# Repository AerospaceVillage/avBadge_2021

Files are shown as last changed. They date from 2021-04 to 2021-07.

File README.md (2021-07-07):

# Aerospace Village Badge 2021

This repository is to document and capture all of the engineering and design work that went into creating the [Aerospace Village](https://aerospacevillage.org) Badge for DefCon 2021.

We hope you enjoy all of the ways to interact with this years badge and learn about Aerospace along the way!

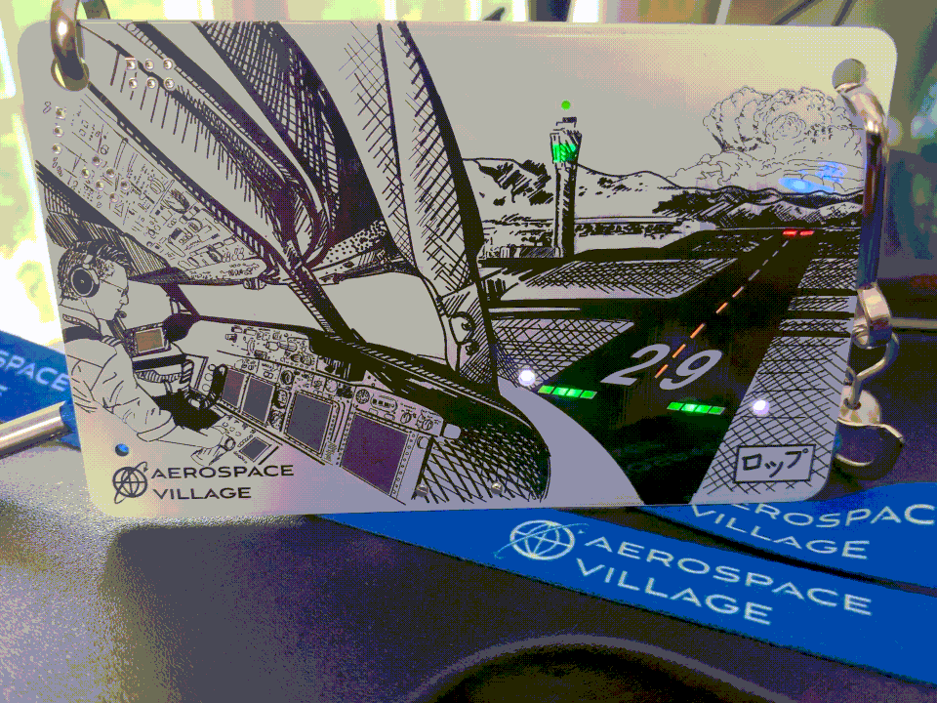
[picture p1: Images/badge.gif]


## Kit Assembly

Instructions for assembling a kit can be found in the Document folder.

  - [Tindie Instructions](https://github.com/daneallen/avBadge_2021/blob/master/Documents/av_badge2021_instructions.pdf)
  - [Instructions sent with kit](https://github.com/daneallen/avBadge_2021/blob/master/Documents/av_badge2021_kit_instructions.pdf)

  ## Arduino Programming
  Using the Arduino IDE Add the correct Boards Manager URL:

      - Under File->Preferences add the following URL https://mcudude.github.io/MiniCore/package_MCUdude_MiniCore_index.json
      - Then with the new Boards Manager options select MiniCore
          - Select the Atmega88

  Steps:

      - Programmer - USBTinyISP
      - Clock - Internal 8MHZ
      - Bootloader - "No bootloader" (Not enough memory to support the bootloader)
      - Sketch -> Upload

      ## AVR Programming

[device permissions help](https://andreasrohner.at/posts/Electronics/How-to-fix-device-permissions-for-the-USBasp-programmer/)

[ttyACM permission](https://stackoverflow.com/questions/40951728/avrdude-ser-open-cant-open-device-dev-ttyacm0-device-or-resource-busy)

```
sudo adduser <username> dialout
$ sudo chmod a+rw /dev/ttyACM0
```

## Hardware
The ATMega88 is programmed with the [Sparkfun Tiny AVR Programmer](https://www.sparkfun.com/products/11801) using the [SparkFun ISP Pogo Adapter](https://www.sparkfun.com/products/11591)

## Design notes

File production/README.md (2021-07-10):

# Production Notes

For ease of mass production a script was made to quickly and reliably program the boards.

The script does the folliwing:
1. Sets the fuses appropriately (i.e. internal 8MHz, etc).
2. Burns a hex file to the chip that essentially ensures the EEPROM address is set to 0.
  - This was to ensure that a "test" part of the code would run to verify LED functionality prior to shipment
3. Burns the actual hex file to the chip

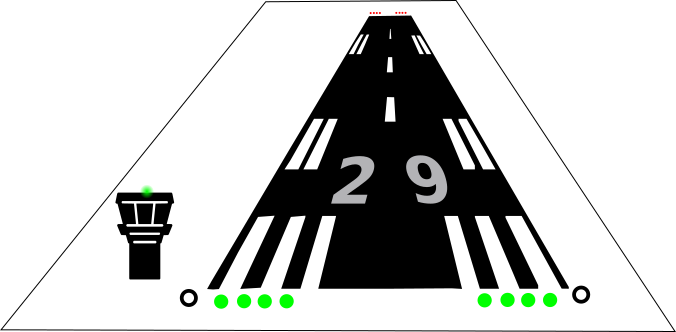
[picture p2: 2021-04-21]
Images/airport_idea.png

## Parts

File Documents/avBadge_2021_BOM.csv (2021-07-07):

Reference | Quantity | Value | Footprint
BT1 | 1 | Battery_Cell | 2479_battery_holder:2479
C1 C2 | 2 | .1uF | Resistors_SMD:R_1206_3216Metric
D1 D2 | 2 | SunLED_RGB_ReverseMount | sunled:XZMDKCBDDG45S-9
D10 D11 D12 | 3 | Yellow LED | sunled:XZMYK45WT-9
D4 D9 | 2 | Blue LED | sunled:XZFBB45S-9
D3 D5 | 2 | White LED | aerospace_badge:led_in-s124ar
D6 D7 | 2 | Green LED | sunled:XZM2CRK45WT-9
D8 | 1 | Red LED | sunled:XZDGK45WT-9
J1 | 1 | AVR-ISP-6 | aerospace_badge:AVR-ISP-6
P1 | 1 | SerialConnector | aerospace_badge:serialConnector
Q1 | 1 | 2N3904 | aerospace_badge:SOT-23-NPN
R13 | 1 | 1K | Resistors_SMD:R_1206_3216Metric
R1 R2 R3 R4 R5 R6 R8 R10 R11 R14 R15 R16 R17 R18 R19 R20 | 16 | 330 | Resistors_SMD:R_1206_3216Metric
R7 R9 R12 | 3 | 10K | Resistors_SMD:R_1206_3216Metric
S1 | 1 | OpenConnections | aerospace_badge:artboard_smooth2
SW1 | 1 | SW_SPDT | aerospace_badge:switch_JS202011SCQN
U1 | 1 | ATmega8-16AU | digikey-footprints:TQFP-32_7x7mm

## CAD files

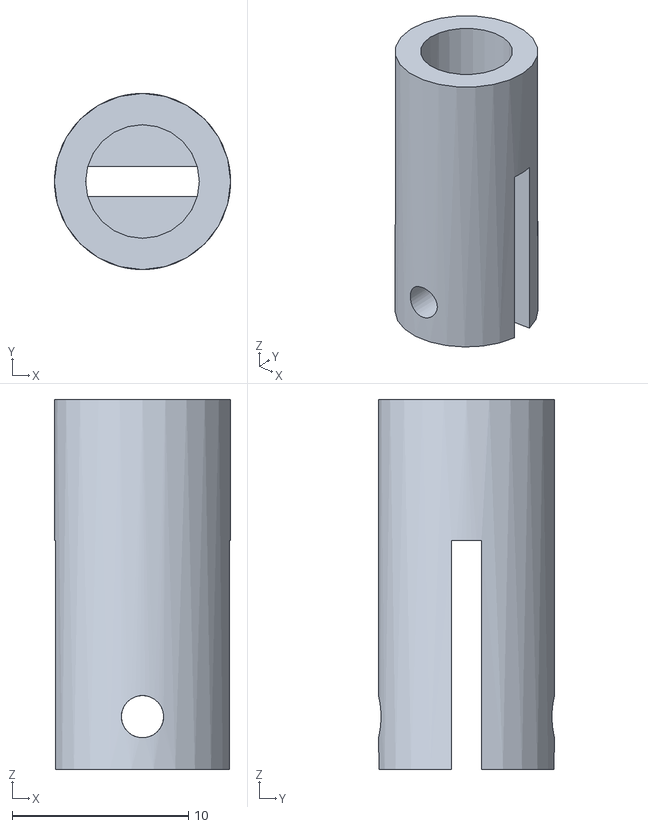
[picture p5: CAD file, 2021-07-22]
avBadgeAttachment.stl
10.0 x 10.0 x 21.0

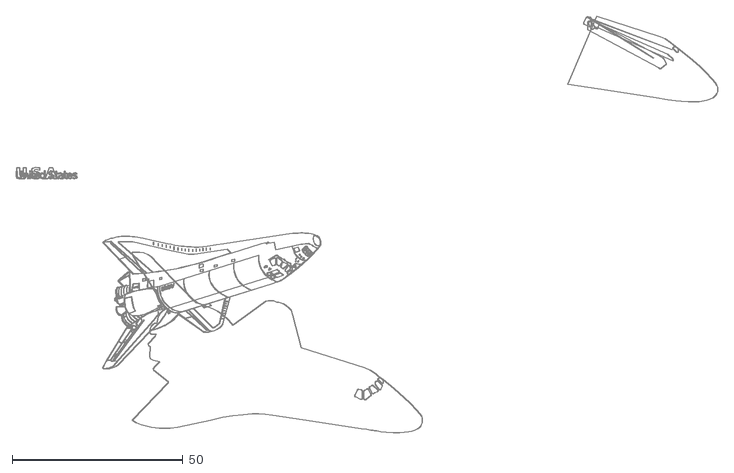
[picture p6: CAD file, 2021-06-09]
Images/space_shuttle_proper.dxf
205.3 x 121.8

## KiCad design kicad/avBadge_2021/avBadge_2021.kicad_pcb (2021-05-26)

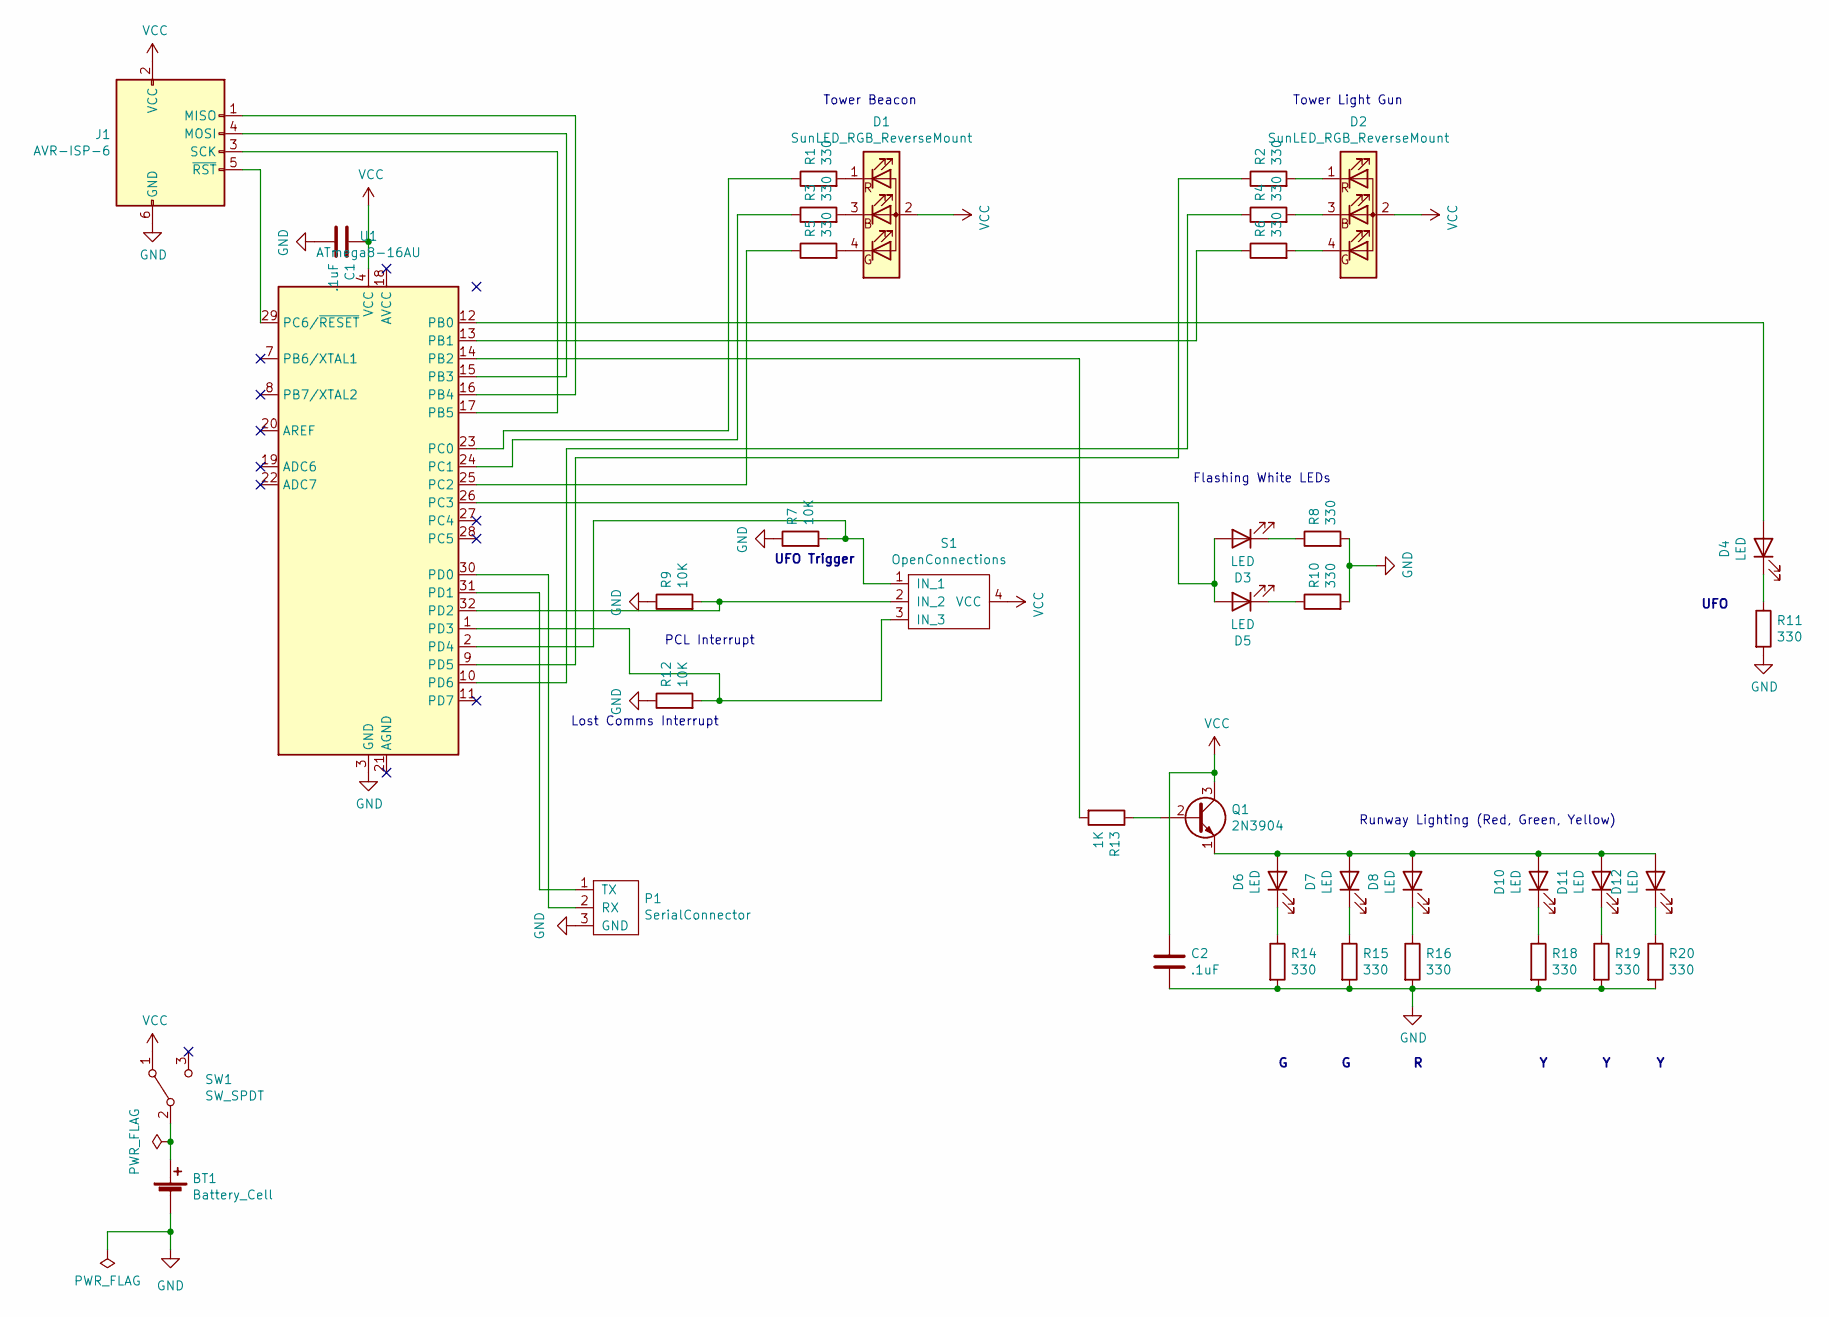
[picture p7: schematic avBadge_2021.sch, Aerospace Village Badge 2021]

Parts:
BT1: Battery_Cell; 2479
C1, C2: .1uF; R_1206_3216Metric
D1, D2: SunLED_RGB_ReverseMount; XZMDKCBDDG45S-9
D3, D5: LED; led_in-s124ar
D4: LED; XZFBB45S-9
D6, D7: LED; XZM2CRK45WT-9
D8: LED; XZDGK45WT-9
D10, D11, D12: LED; XZMYK45WT-9
J1: AVR-ISP-6
P1: SerialConnector; serialConnector
Q1: 2N3904; SOT-23-NPN
R1, R2, R3, R4, R5, R6, R8, R10, R11, R14, R15, R16, R18, R19, R20: 330; R_1206_3216Metric
R7, R9, R12: 10K; R_1206_3216Metric
R13: 1K; R_1206_3216Metric
S1: OpenConnections; artboard2
SW1: SW_SPDT; switch_JS202011SCQN
U1: ATmega8-16AU; TQFP-32_7x7mm

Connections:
GND: BT1.2 (-), C1.2, C2.2, J1.6 (GND), P1.3 (GND), R7.1, R8.2, R9.1, R10.2, R11.2, R12.1, R14.2, R15.2, R16.2, R18.2, R19.2, R20.2, U1.3 (GND), U1.5 (GND)
unnamed: BT1.1 (+), SW1.2 (B)
unnamed: D1.1 (R), R1.2
unnamed: D1.3 (G), R3.2
unnamed: D1.4 (B), R5.2
unnamed: D2.1 (R), R2.2
unnamed: D2.3 (G), R4.2
unnamed: D2.4 (B), R6.2
unnamed: D3.1 (K), R8.1
unnamed: D3.2 (A), D5.2 (A), U1.26 (PC3)
unnamed: D4.1 (K), R11.1
unnamed: D4.2 (A), U1.12 (PB0)
unnamed: D5.1 (K), R10.1
unnamed: D6.1 (K), R14.1
unnamed: D7.1 (K), R15.1
unnamed: D8.1 (K), R16.1
unnamed: D10.1 (K), R18.1
unnamed: D6.2 (A), D7.2 (A), D8.2 (A), D10.2 (A), D11.2 (A), D12.2 (A), Q1.1 (E)
unnamed: D11.1 (K), R19.1
unnamed: D12.1 (K), R20.1
unnamed: J1.1 (MISO), U1.16 (PB4)
unnamed: J1.3 (SCK), U1.17 (PB5)
unnamed: J1.4 (MOSI), U1.15 (PB3)
unnamed: J1.5 (~RST), U1.29 (PC6/~RESET)
unnamed: P1.1 (TX), U1.31 (PD1)
unnamed: P1.2 (RX), U1.30 (PD0)
unnamed: Q1.2 (B), R13.1
unnamed: R1.1, U1.23 (PC0)
unnamed: R2.1, U1.9 (PD5)
unnamed: R3.1, U1.24 (PC1)
unnamed: R4.1, U1.10 (PD6)
unnamed: R5.1, U1.25 (PC2)
unnamed: R6.1, U1.13 (PB1)
unnamed: R7.2, S1.1 (IN_1), U1.2 (PD4)
unnamed: R9.2, S1.2 (IN_2), U1.32 (PD2)
unnamed: R12.2, S1.3 (IN_3), U1.1 (PD3)
unnamed: R13.2, U1.14 (PB2)
VCC: C1.1, C2.1, D1.2 (A), D2.2 (A), J1.2 (VCC), Q1.3 (C), S1.4 (VCC), SW1.1 (A), U1.4 (VCC), U1.6 (VCC)

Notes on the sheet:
Tower Beacon
Tower Light Gun
Flashing White LEDs
Runway Lighting (Red, Green, Yellow)
PCL Interrupt
Lost Comms Interrupt
UFO
UFO Trigger

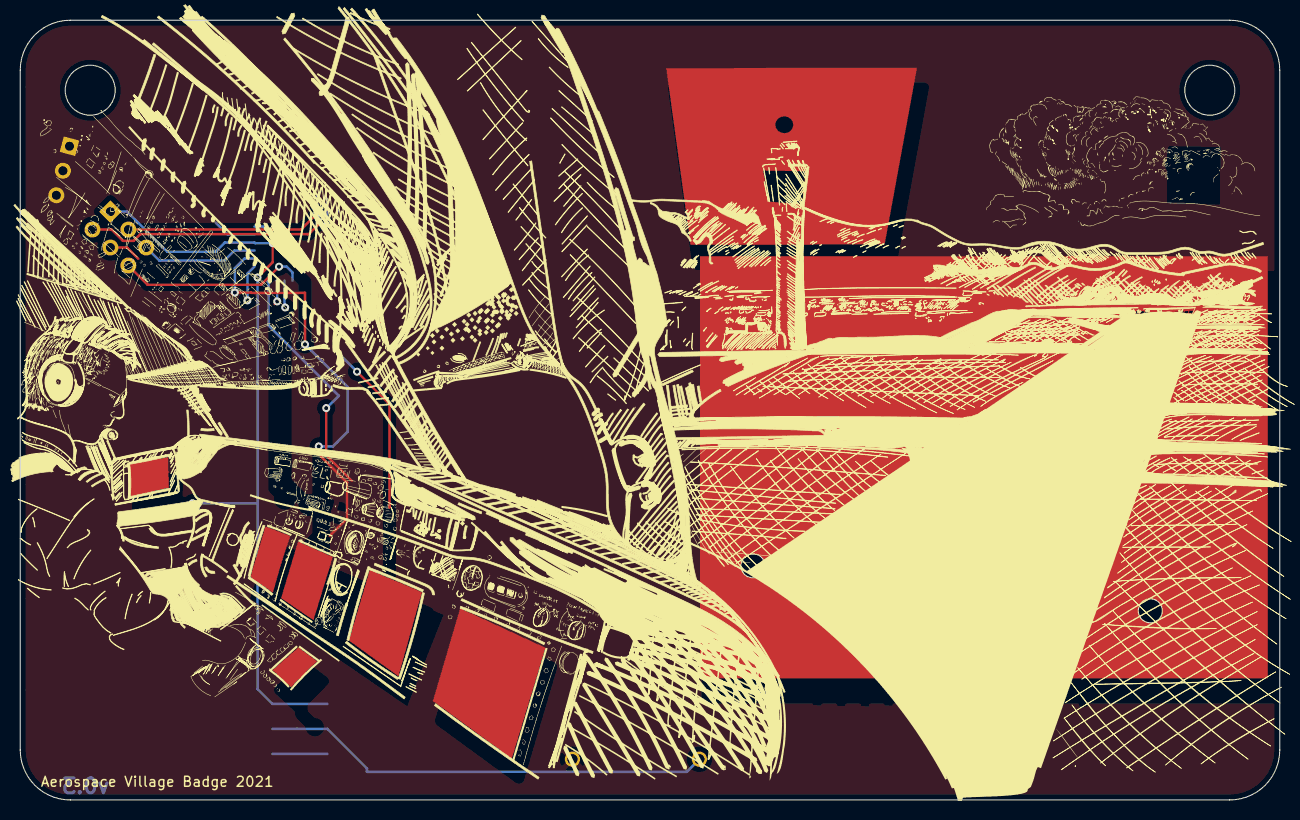
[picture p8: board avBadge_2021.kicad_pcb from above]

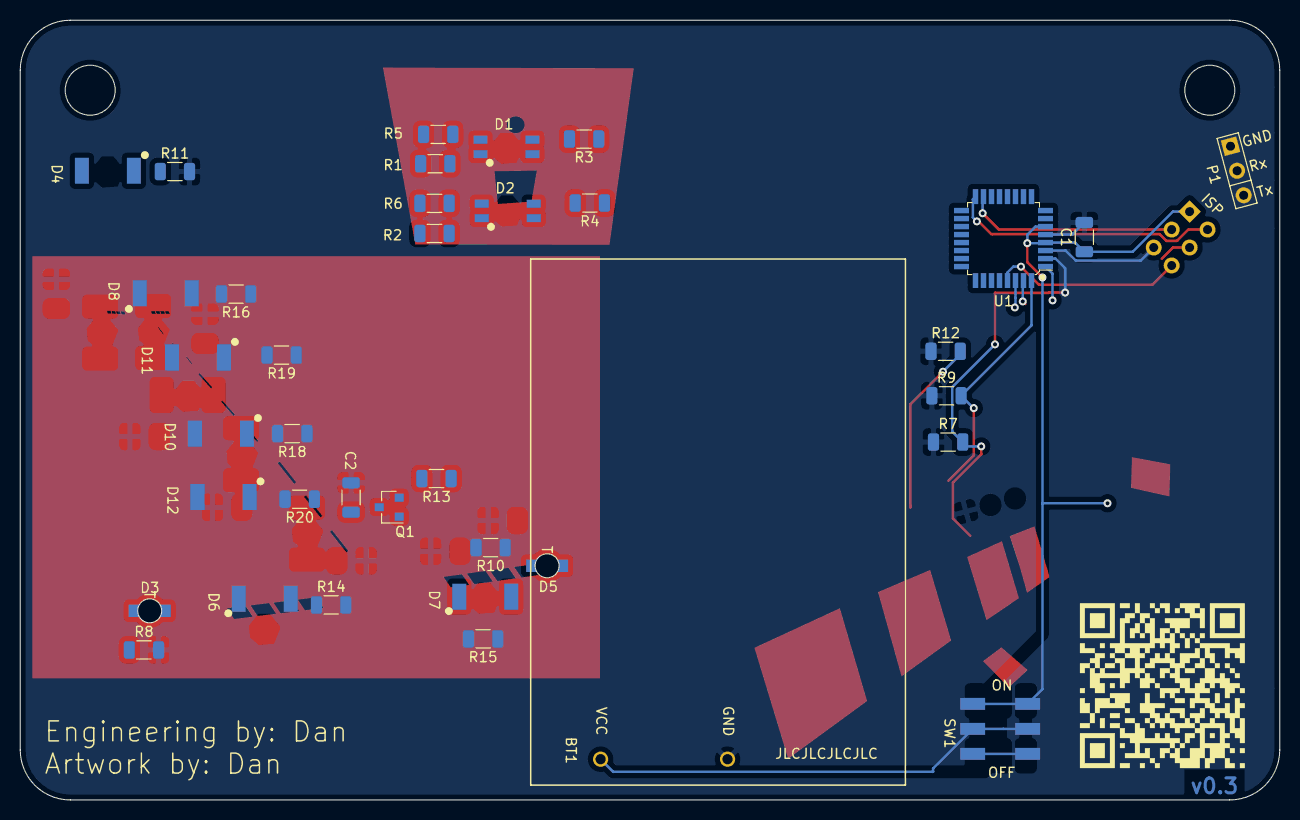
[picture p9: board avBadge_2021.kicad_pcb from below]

Board: 2 copper layers, 126.0 x 78.0 mm, 40 parts (38 on the bottom side), 38 nets.

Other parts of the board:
QR*****: qrc

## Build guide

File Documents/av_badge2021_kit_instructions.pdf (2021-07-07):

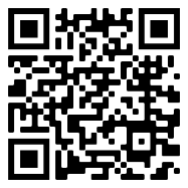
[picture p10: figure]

The complete assembly instructions for the Aerospace Village badge 2021 are found on the Tindie website:

https://www.tindie.com/stores/aero_village/

The complete assembly instructions for the Aerospace Village badge 2021 are found on the Tindie website:

https://www.tindie.com/stores/aero_village/

The complete assembly instructions for the Aerospace Village badge 2021 are found on the Tindie website:

https://www.tindie.com/stores/aero_village/

The complete assembly instructions for the Aerospace Village badge 2021 are found on the Tindie website:

https://www.tindie.com/stores/aero_village/

The complete assembly instructions for the Aerospace Village badge 2021 are found on the Tindie website:

https://www.tindie.com/stores/aero_village/

The complete assembly instructions for the Aerospace Village badge 2021 are found on the Tindie website:

https://www.tindie.com/stores/aero_village/

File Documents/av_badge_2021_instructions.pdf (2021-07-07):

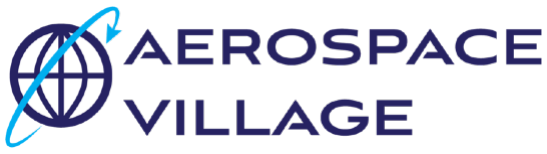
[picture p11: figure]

# Aerospace Village Badge 2021 - Assembly Instructions

# Components

# Notes:

## - The microcontroller has already been soldered to the board to that it could be preprogrammed for your kit. The picture displaying the microcontroller orientation is

provided for reference.

## - Components not specifically identified with an orientation marking simply need to be

connected their respective copper traces (i.e. resistors[R], capacitors[C], transistor[Q])

Reference | Quantity | Value | Footprint
BT1 | 1 | Battery_Cell | 2479_battery_holder:2479
C1 C2 | 2 | .1uF | Resistors_SMD:R_1206_3216Metric
D1 D2 | 2 | RGB LED | sunled:XZMDKCBDDG45S-9
D10-12 | 3 | Yellow LED | sunled:XZMYK45WT-9
D4 D9 | 2 | Blue LED | sunled:XZFBB45S-9
D3 D5 | 2 | White LED | aerospace_badge:led_in-s124ar
D6 D7 | 2 | Green LED | sunled:XZM2CRK45WT-9
D8 | 1 | Red LED | sunled:XZDGK45WT-9
Q1 | 1 | 2N3904 | aerospace_badge:SOT-23-NPN
R13 | 1 | 1K | Resistors_SMD:R_1206_3216Metric
R1-6, R8 R10, R11 R14-20 | 16 | 330 | Resistors_SMD:R_1206_3216Metric
R7 R9 R12 | 3 | 10K | Resistors_SMD:R_1206_3216Metric
SW1 | 1 | SW_SPDT | aerospace_badge:switch_JS202011SCQN
U1 | 1 | ATmega8-16AU | digikey-footprints:TQFP-32_7x7mm

## Red arrow used to indicate orientation of component and PCB dots/circles

## Green arrow used to indicate orientation of component and PCB “T” shape. Both should be

oriented in the same manner.

# Component Orientation

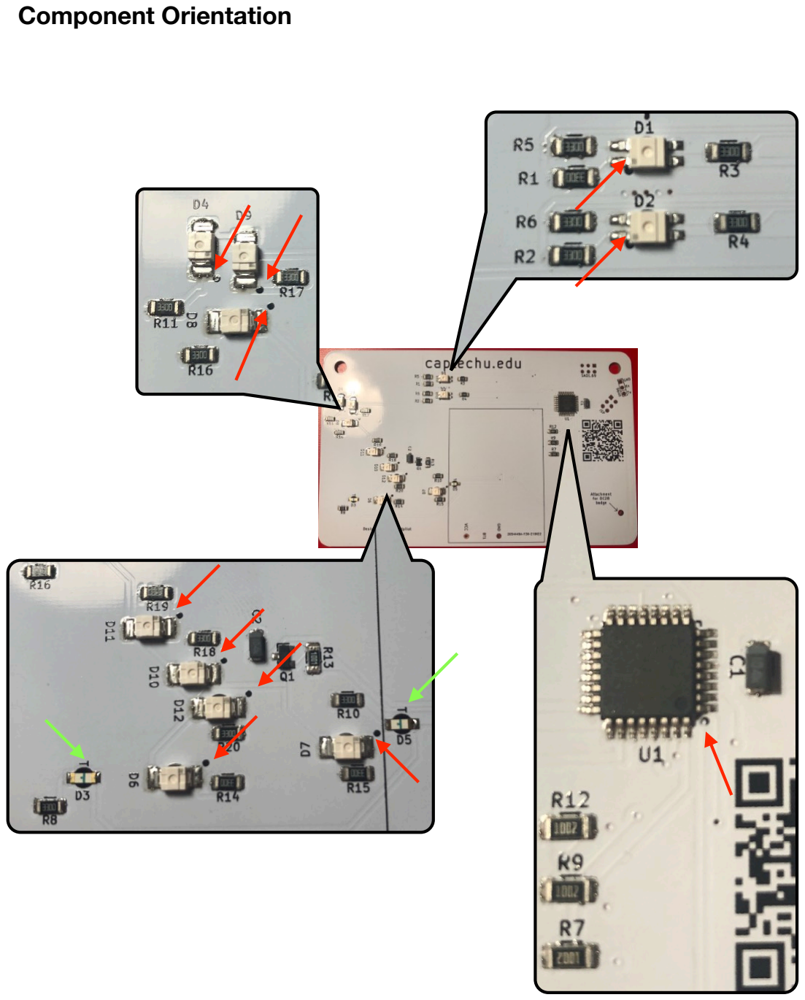
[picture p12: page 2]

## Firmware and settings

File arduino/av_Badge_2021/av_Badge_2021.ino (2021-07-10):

#include "Arduino.h"
#include <EEPROM.h>

// Pin mappings
#define g_beacon_R 14
#define g_beacon_G 16
#define g_beacon_B 15

#define g_tower_R 5
#define g_tower_G 9
#define g_tower_B 6

#define g_button 3
#define g_rwy_flashing 17 
#define g_rwy 10

#define g_UFO_LED 8

#define g_UFO_INPUT 4
#define g_LOST_COMMS_INPUT 3
#define g_PCL_INPUT 2


short rwy_intensity[] = {0, 20, 50, 200};
short rwy_intensity_index = 1;
short rwy_intensity_count = 0;
short rwy_intensity_limit = 2000; // How long the user has hold the circuit closed for it to trigger ON (clock cyles)

const int rwy_edge_lights_ON_TIME = 5;
const int rwy_edge_lights_OFF_TIME = 2000;
boolean rwy_edge_lights_ON_STATE = true;
unsigned long previousMillis_rwy_edge_lights = 0;

const int beacon_ON_TIME = 900;
const int beacon_OFF_TIME = 3000;
boolean beacon_ON_STATE = true;
unsigned long previousMillis_beacon = 0;
boolean beacon_is_green = true;   // false is then percieved as White

const int tower_gun_ON_TIME = 500;
const int tower_gun_OFF_TIME = 400;
boolean tower_gun_ON_STATE = true;
unsigned long previousMillis_tower_gun = 0;
boolean tower_gun_is_green = false;   // false is then percieved as RED for exercise extreme caution
boolean tower_light_gun_is_ON = false;
short lost_comms_count = 0;
short lost_comms_limit = 10000;


boolean UFO_isOn = false;
short UFO_count = 0;
short UFO_count_limit = 20000; // How long the user has hold the circuit closed for it to trigger ON (clock cyles)

//EEPROM addresses for persistant state across power cycles.
#define initial_setup 0
#define UFO_boolean_address 1

void serial_clear(){
  for(int i=0; i<100; i++){
    Serial.print("\r\n");
  }
}

void serial_menu_display(short menu_index){

  serial_clear();
  switch (menu_index) {
    case 1:
      Serial.println(F("Airport Information\r\n"));
      Serial.println(F("KASV\r\nAirport use:   Open to the public\r\nElevation: 203 ft\r\nTime Zone: UTC -7 (UTC -8 during Standard Time)"));
      Serial.println(F("RWY: 29/11\r\nATIS: 125.85\r\nGND: 121.9\r\nTWR: 119.35\r\nDEFCON Approach: 120.45"));
      Serial.println(F("\nPress ENTER to return to main menu"));      
      break;
      
    case 2:
      Serial.println(F("Aerospace Village Information\r\n"));
      Serial.println(F("Build, inspire, and promote an inclusive community of next-generation aerospace cybersecurity expertise and leaders."));
      Serial.println(F("To learn more about the community, be sure to check out: aerospacevillage.org"));
      Serial.println(F("\nPress ENTER to return to main menu"));
      break;

    case 3:
      Serial.println(F("Current PIREPS\r\n"));
      Serial.println(F("05 AUG 2021 0430Z: Pilot reported an \"unidentified flying object\" in the distance while on short final to RWY29."));
      Serial.println(F("05 AUG 2021 0435Z: Police reports of strange blue lights to the WNW of the airfield.\n"));
      Serial.println(F("To report a PIREP please send an email to pirep@aerospacevillage.org with the subject line: \"KASV PIREP\""));
      Serial.println(F("\nPress ENTER to return to main menu"));
      break;

    case 4:
      Serial.println(F("About the Badge\r\n"));
      Serial.println(F("Designed by @cybertestpilot, github.com/daneallen/avBadge_2021"));
      Serial.println(F("Artwork by Dan Ropp - flysurreal.com\n"));
      Serial.println(F("Have you connected the MFDs in varying combinations?"));
      Serial.println(F("Do you know what \"Lost Comms\" would look like from the control tower?"));
      Serial.println(F("Are you familiar with Pilot Controlled Lighting?"));
      Serial.println(F("Let us know what you think of the Badge!"));
      Serial.println(F("\nPress ENTER to return to main menu"));
      break;


    case 0:
    default:
      
      Serial.println(F("Welcome to the Aerospace Village Airport (KASV)"));
      Serial.println(F("Select from an available option to learn more:"));
      Serial.println(F("\t1. Airport Information"));
      Serial.println(F("\t2. Aerospace Village Information"));
      Serial.println(F("\t3. View current PIREPS"));
      Serial.println(F("\t4. About the Badge"));
      Serial.println(F("\n\nEnter the desired menu number"));
      break;      
  }  
}

void setup() {

  Serial.begin(9600);
  serial_menu_display(0);
  
  pinMode(g_beacon_R, OUTPUT);
  pinMode(g_beacon_G, OUTPUT);
  pinMode(g_beacon_B, OUTPUT);
  
  pinMode(g_tower_R, OUTPUT);
  pinMode(g_tower_G, OUTPUT);
  pinMode(g_tower_B, OUTPUT);
 
  pinMode(g_rwy_flashing, OUTPUT);  
  pinMode(g_rwy, OUTPUT);

  pinMode(g_UFO_LED, OUTPUT);

  //EEPROM.write(initial_setup, 0);
  
  if(EEPROM.read(initial_setup) == 0){
    digitalWrite(g_UFO_LED, HIGH);    
    EEPROM.write(initial_setup, 1); //only do this once to help with manufacturing so as to op check functionality
    EEPROM.write(UFO_boolean_address, 0); //only do this once to help with manufacturing so as to op check functionality
    delay(5000);
    digitalWrite(g_UFO_LED, LOW);
    UFO_isOn = false;
    
  }else{
    UFO_isOn = EEPROM.read(UFO_boolean_address);
    tower_light_gun_is_ON = UFO_isOn; //make the tower light gun match what the UFO is doing to "proceed with caution"
    digitalWrite(g_UFO_LED, UFO_isOn);
  }

  // User input on the artwork.
  pinMode(g_UFO_INPUT, INPUT);
  pinMode(g_LOST_COMMS_INPUT, INPUT);
  pinMode(g_PCL_INPUT, INPUT);
}



/*
* Helper function to handle the aysmmetric timing of the runway flashing lights.
* To create the desired timing the lights are pulsed in a quick burst.
*/
void runwayEdgeLight()
{
  unsigned long currentMillis = millis();

  if(rwy_edge_lights_ON_STATE){
    if(currentMillis >= previousMillis_rwy_edge_lights + rwy_edge_lights_ON_TIME){
        rwy_edge_lights_ON_STATE = !rwy_edge_lights_ON_STATE;
        previousMillis_rwy_edge_lights = currentMillis;        
        digitalWrite(g_rwy_flashing, LOW);
     }
  }else{
    if(currentMillis >= previousMillis_rwy_edge_lights + rwy_edge_lights_OFF_TIME){
      rwy_edge_lights_ON_STATE = !rwy_edge_lights_ON_STATE;
      previousMillis_rwy_edge_lights = currentMillis;
      digitalWrite(g_rwy_flashing, HIGH);
    }
  }   
}

/*
* Helper function to handle the aysmmetric timing of the airfield beacon lights.
* To create the desired timing the lights are pulsed in a quick burst.
*/
void beaconLight()
{
  unsigned long currentMillis = millis();

  if(beacon_ON_STATE){
    if(currentMillis >= previousMillis_beacon + beacon_ON_TIME){
        beacon_ON_STATE = !beacon_ON_STATE;
        previousMillis_beacon = currentMillis;
        digitalWrite(g_beacon_R, HIGH);
        digitalWrite(g_beacon_G, HIGH);
        digitalWrite(g_beacon_B, HIGH);        
     }
  }else{
    if(currentMillis >= previousMillis_beacon + beacon_OFF_TIME){
      beacon_ON_STATE = !beacon_ON_STATE;
      previousMillis_beacon = currentMillis;

      // need to write the correct color
      if(beacon_is_green){
        digitalWrite(g_beacon_R, HIGH);
        digitalWrite(g_beacon_G, LOW);
        digitalWrite(g_beacon_B, HIGH);
        beacon_is_green = !beacon_is_green;
      }else{
        // Treat it as a white light
        digitalWrite(g_beacon_R, LOW);
        digitalWrite(g_beacon_G, LOW);
        digitalWrite(g_beacon_B, LOW);
        beacon_is_green = !beacon_is_green;
      }      
    }
  }   
}

/*
* Helper function to handle the timing of the tower light gun.
* To create the desired timing the lights are pulsed in a quick burst.
*/
void towerLightGun()
{
  unsigned long currentMillis = millis();

  if(tower_light_gun_is_ON){

    if(tower_gun_ON_STATE){
      if(currentMillis >= previousMillis_tower_gun + tower_gun_ON_TIME){
          tower_gun_ON_STATE = !tower_gun_ON_STATE;
          previousMillis_tower_gun = currentMillis;
          digitalWrite(g_tower_R, HIGH);
          digitalWrite(g_tower_G, HIGH);
          digitalWrite(g_tower_B, HIGH);        
       }
    }else{
      if(currentMillis >= previousMillis_tower_gun + tower_gun_OFF_TIME){
        tower_gun_ON_STATE = !tower_gun_ON_STATE;
        previousMillis_tower_gun = currentMillis;
  
        // need to write the correct color
        if(tower_gun_is_green){
          digitalWrite(g_tower_R, HIGH);
          digitalWrite(g_tower_G, LOW);
          digitalWrite(g_tower_B, HIGH);
          tower_gun_is_green = !tower_gun_is_green;
        }else{
          // Treat it as a red light
          digitalWrite(g_tower_R, LOW);
          digitalWrite(g_tower_G, HIGH);
          digitalWrite(g_tower_B, HIGH);
          tower_gun_is_green = !tower_gun_is_green;
        }        
      }
    }
  }else{
    //The light gun is OFF, just show normal yellow
    digitalWrite(g_tower_R, LOW);
    digitalWrite(g_tower_G, LOW);
    digitalWrite(g_tower_B, HIGH);
  }
}

void maintain_UFO(){
  if(digitalRead(g_UFO_INPUT) == HIGH){
    UFO_count += 1;
        
    if(UFO_count >= UFO_count_limit){
      UFO_isOn = !UFO_isOn;
      EEPROM.write(UFO_boolean_address, byte(UFO_isOn));  //Write the state to memory for persistance
      UFO_count = 0;
      tower_light_gun_is_ON = UFO_isOn; //make the tower light gun match what the UFO is doing to "proceed with caution"

      serial_clear();
      
      Serial.println(F("\r\n\r\nDo you believe?\r\n\r\n"));
      Serial.println(F("    .-\"\"\"\"-.        .-\"\"\"\"-."));
      Serial.println(F("   /        \\      /        \\"));
      Serial.println(F("  /_        _\\    /_        _\\"));
      Serial.println(F(" // \\      / \\\\  // \\      / \\\\"));
      Serial.println(F(" |\\__\\    /__/|  |\\__\\    /__/|"));
      Serial.println(F("  \\    ||    /    \\    ||    /"));
      Serial.println(F("   \\        /      \\        /"));
      Serial.println(F("    \\  __  /        \\  __  /"));
      Serial.println(F("     '.__.'          '.__.'"));
      Serial.println(F("      |  |            |  |"));
      Serial.println(F("      |  |            |  |"));
      Serial.println(F("\r\n\r\nDo you believe?"));      
    }
  }else{
    UFO_count = 0;
  }
  
  if(UFO_isOn == true){
    digitalWrite(g_UFO_LED, HIGH);
  }else{
    digitalWrite(g_UFO_LED, LOW);
  }
}

void maintain_LOST_COMMS(){
  if(digitalRead(g_LOST_COMMS_INPUT) == HIGH){
    lost_comms_count += 1;
    if(lost_comms_count >= lost_comms_limit){
      tower_light_gun_is_ON = !tower_light_gun_is_ON;
      lost_comms_count = 0;
    }
  }else{
    lost_comms_count = 0;
  }
}

void maintain_PCL(){
  if(digitalRead(g_PCL_INPUT) == HIGH){
    rwy_intensity_count += 1;
    if(rwy_intensity_count >= rwy_intensity_limit){
      rwy_intensity_index += 1;
      if(rwy_intensity_index >= 4){
        rwy_intensity_index = 0;
      }
      rwy_intensity_count = 0;
    }
  }else{
    rwy_intensity_count = 0;
  }

  analogWrite(g_rwy, rwy_intensity[rwy_intensity_index]);
}

void loop() {

  // helper functions to modularize the behavior of the different lighting packages.
  runwayEdgeLight();
  beaconLight();
  towerLightGun();
  
  // helper functions for user input maintenance
  maintain_UFO();
  maintain_LOST_COMMS();
  maintain_PCL();

  // Service Serial input/output

  int user_selection = 0; // for incoming serial data

  // reply only when you receive data:
  if (Serial.available() > 0) {
    // read the incoming byte:
    user_selection = (short)Serial.parseInt();
    Serial.print(String(user_selection));
    serial_menu_display(user_selection);

  }  
}

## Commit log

2021-04-21 initial commit for prototype badge
    [avBadge_2021-B_Cu.gbl, avBadge_2021-B_Mask.gbs, avBadge_2021-B_Paste.gbp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]
2021-05-01 arduino code updates and manufactured v01 gerbers completed.
    [avBadge_2021.kicad_pcb, avBadge_2021.sch]
2021-05-05 arduino update to include pulsing lights as desired.
    [avBadge_2021.sch]
2021-05-07 refactor of kicad files working through incorporation of art and new MCU design.
    [avBadge_2021.kicad_pcb, avBadge_2021.sch, idea_mapping.ods]
2021-05-07 v0.2 gerber builtout and sent for fabrication.
    [avBadge_2021-B_Cu.gbl, avBadge_2021-B_Mask.gbs, avBadge_2021-B_Paste.gbp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]
2021-05-25 incremental improvements to art, edgecuts, layout
    [avBadge_2021.kicad_pcb, avBadge_2021.sch, avBadge_2021_grouped.ods]
2021-05-26 artwork cleanup and general tweaks. Incremental save.
    [avBadge_2021.kicad_pcb, avBadge_2021.sch]
2021-05-29 v03. Updated art and everything that goes along.
    [avBadge_2021-B_Cu.gbl, avBadge_2021-B_Mask.gbs, avBadge_2021-B_Paste.gbp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]
2021-06-09 multiple changes, now on v04
    [avBadge_2021-B_Cu.gbl, avBadge_2021-B_Mask.gbs, avBadge_2021-B_Paste.gbp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]
2021-06-09 v04 as sent to for fabrication.
    [avBadge_2021-B_Cu.gbl, avBadge_2021-B_Mask.gbs, avBadge_2021-B_Paste.gbp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]
2021-07-07 file organization, Readme update, build instructions.
    [avBadge_2021.ods, avBadge_2021_BOM.csv, avBadge_2021_BOM.ods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]
2021-07-07 rename Images folder and Readme with gif
    [space_shuttle_proper.dxf]
2021-07-10 script used to program all shipped boards... fingers crossed :-)
2021-07-22 working attachment for last years badge.
    [avBadgeAttachment.stl]
